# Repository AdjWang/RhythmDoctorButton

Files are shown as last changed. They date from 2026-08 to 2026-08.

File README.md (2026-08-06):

# Rhythm Doctor Button

<p align="center">
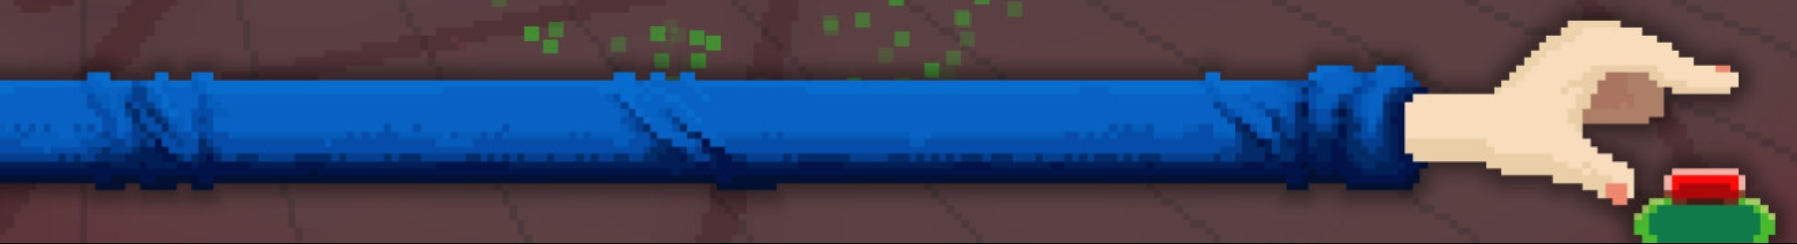
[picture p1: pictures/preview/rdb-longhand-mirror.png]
Mirrored ingame snapshot
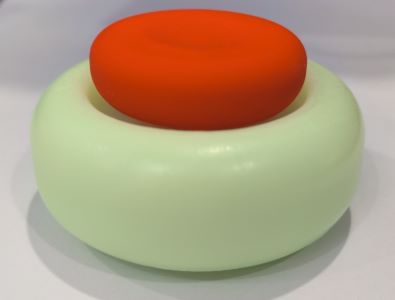
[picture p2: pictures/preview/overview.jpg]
Button overview
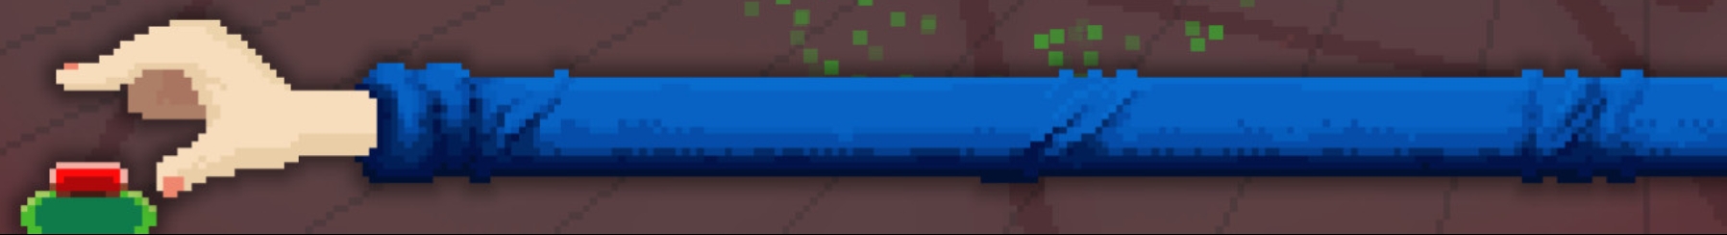
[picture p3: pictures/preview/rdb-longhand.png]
Ingame snapshot
  
</p>

一个用来玩[节奏医生](https://store.steampowered.com/app/774181/Rhythm_Doctor/)的按钮：

- Type-C 有线 + 蓝牙双模键盘，只有空格。
- 理论最长待机 34 天。
- 热插拔 5 脚机械轴。
- 模拟游戏按钮灯光。
- 串口可调灯光开关和亮度。

## 配置

- NRF52840 主控。
- 800 mAh 锂电池。
- 凯华 BOX 知秋轴。
- 1 颗轴体 LED，12 颗背光 LED。
- 磁吸底盖，带防滑脚垫。

## 工程文件

- firmware: 固件

- model: 外壳模型

- schematic: 电路 / PCB 图

制作流程参考 [make.md](make.md)

<h1 align="center">好了，废话不多说，Rhythm Doctor, 启动！</h1>

<p align="center">
  Rhythm Doctor button animation
</p>

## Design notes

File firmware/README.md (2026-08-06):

# Firmware

## Setup environment

Guide: https://docs.zephyrproject.org/4.4.0/develop/getting_started/index.html

```
uv init
uv add west
uv run west update
uv run west packages pip | xargs uv pip install
```

## Build

```
uv run west build -p always -b nrf52840dk/nrf52840 app -- -DAPP_BIN=main
```

Tests:

```
uv run west build -p always -b nrf52840dk/nrf52840 app -- -DAPP_BIN=uart
uv run west build -p always -b nrf52840dk/nrf52840 app -- -DAPP_BIN=cmd
uv run west build -p always -b nrf52840dk/nrf52840 app -- -DAPP_BIN=storage
uv run west build -p always -b nrf52840dk/nrf52840 app -- -DAPP_BIN=pwm_led
uv run west build -p always -b nrf52840dk/nrf52840 app -- -DAPP_BIN=key
uv run west build -p always -b nrf52840dk/nrf52840 app -- -DAPP_BIN=adc
uv run west build -p always -b nrf52840dk/nrf52840 app -- -DAPP_BIN=usb
uv run west build -p always -b nrf52840dk/nrf52840 app -- -DAPP_BIN=ble
```

## Flash program

```
cp build/zephyr/zephyr.uf2 /media/$USER/NICENANO/
```

## Flash bootloader

```
pyocd flash -t nrf52840 -f 1M -e chip --format hex scripts/nice_nano_bootloader-0.11.0_s140_6.1.1.hex
```

## Power consumption

- BLE connected, idle: 0.96 mA
- BLE connected, all leds on: 35.75 mA
- BLE advertising, without led: 1.27 mA

## Persisted settings

Uart on usb cdc is enabled to set arguments through console. Input `key = value` then enter to new line to accept.

Available settings:

- enable_led = true/false
- key_led_brightness = 0.0~1.0
- bkg_led_brightness = 0.0~1.0
- factory_reset = true

Default value:

- enable_led = true
- key_led_brightness = 0.2
- bkg_led_brightness = 0.08

> Adjust led brightness would change default power consumption.

Example outputs:

- Empty line:

    ```
    cmd parse error: code=cmd_empty_line message=empty command at position 0 in ''
    ```

- Set value:

    ```
    enable_led=false
    saved command: key=enable_led value=false
    ```

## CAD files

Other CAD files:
model/RhythmDoctorButton-v7.f3d

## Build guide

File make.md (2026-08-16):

# 制作流程

> 模型和电路在拍照留念后有小幅改动，最新版本细节可能与图片有所差异。

## 电路

使用[嘉立创 `EDA`](https://lceda.cn/)绘制，电路图 `DRC` 生成 `1` 个电源网络短接警告，`PCB` `DRC` 生成多个板载天线的连接和间距警告，均可忽略，希望软件后续版本可以妥善处理这些场景。

<p align="center">
  Schematic
</p>

<p align="center">
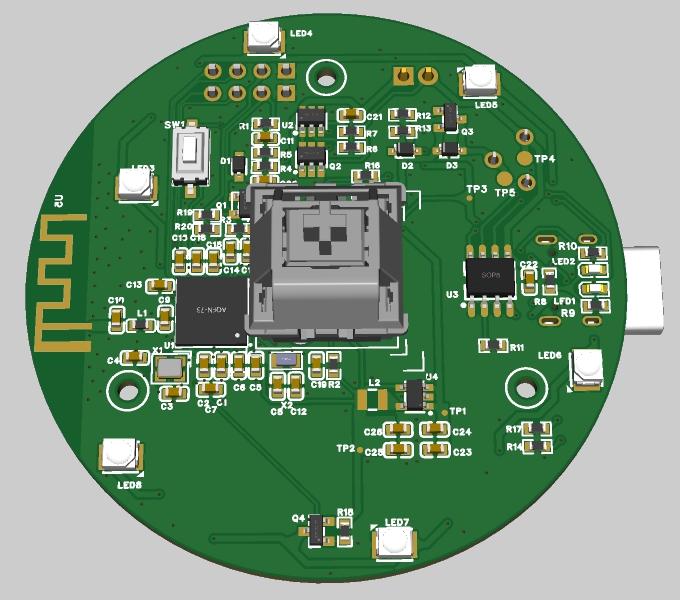
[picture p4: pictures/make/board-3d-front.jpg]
Board 3d front
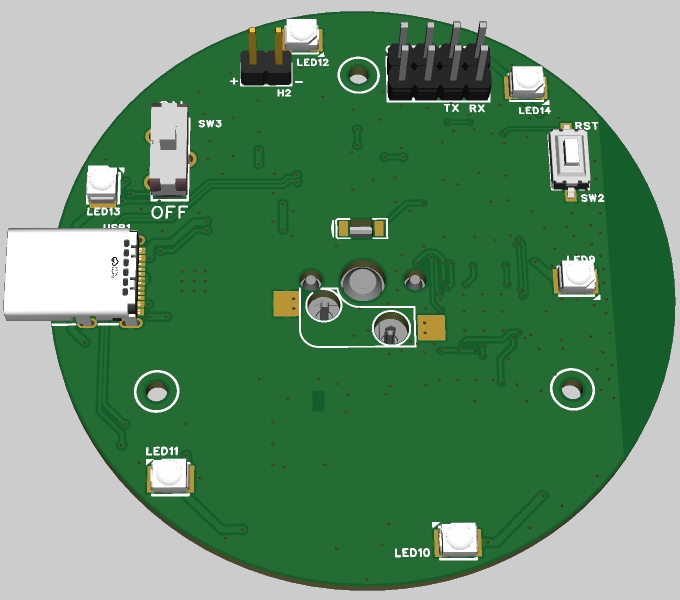
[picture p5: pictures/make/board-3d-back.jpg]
Board 3d back
  
</p>

焊接，安装电池。

<p align="center">
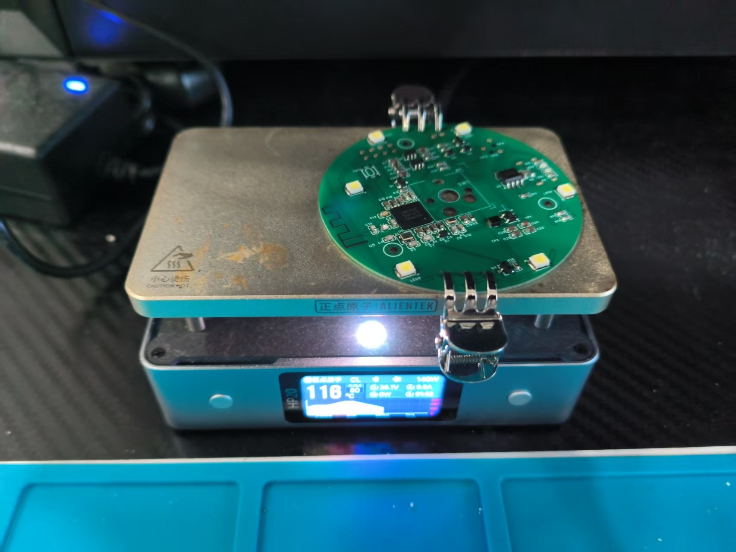
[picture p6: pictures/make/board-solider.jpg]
Board solider
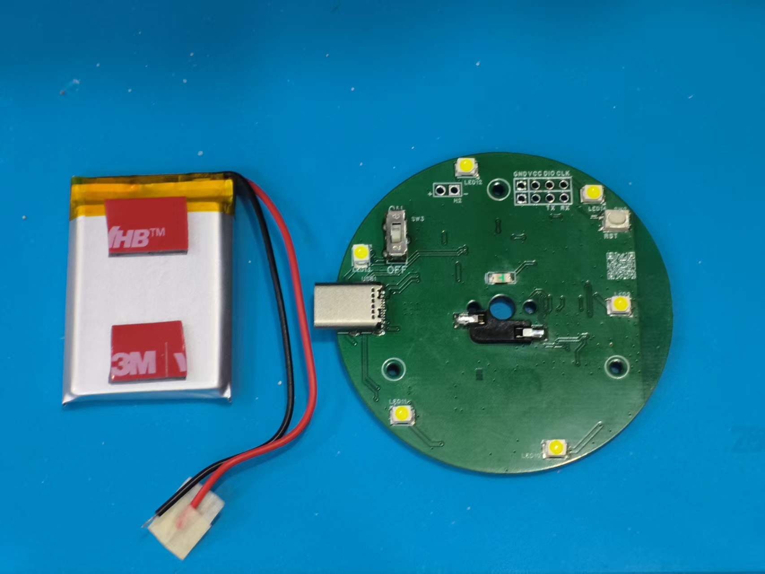
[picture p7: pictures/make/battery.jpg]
Add battery
  
</p>

成品电路板。

<p align="center">
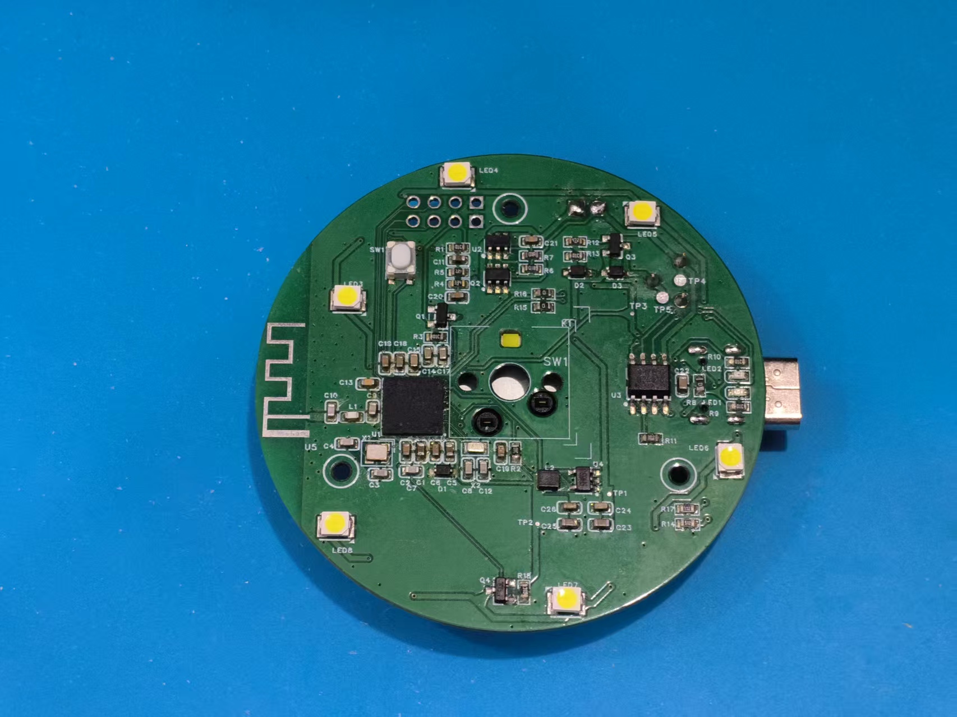
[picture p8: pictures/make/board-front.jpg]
Board front
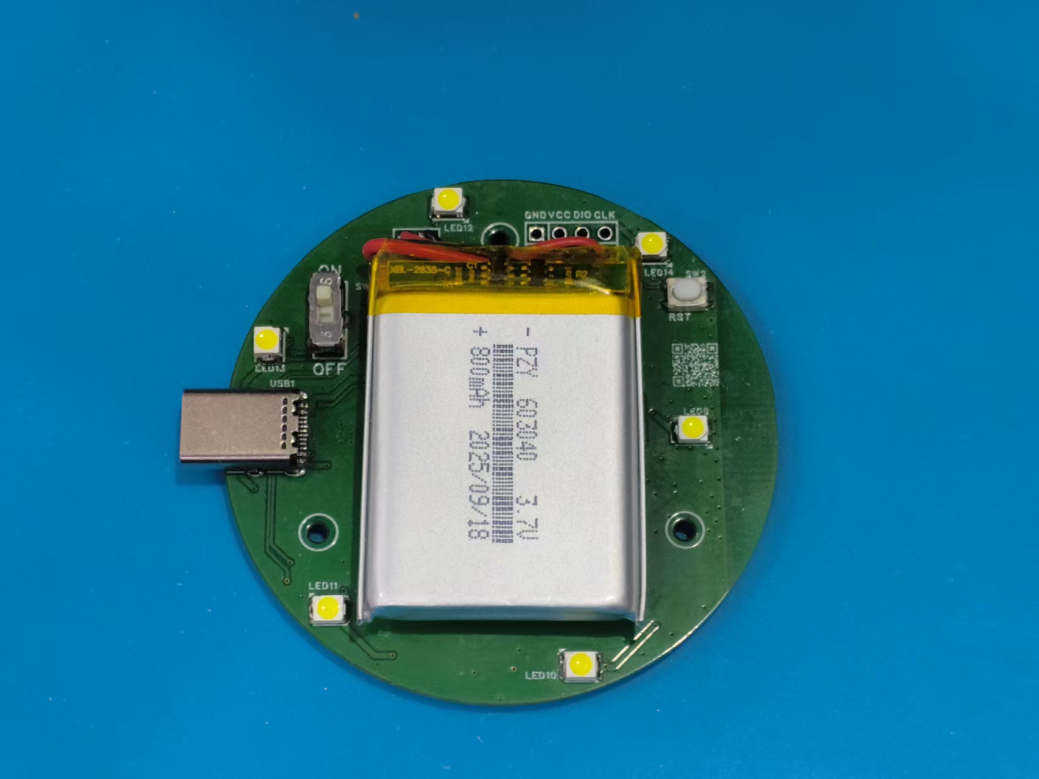
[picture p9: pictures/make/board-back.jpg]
Board back
  
</p>

### 注意事项：

- 材质使用 `FR-4` 即可。
- 板厚 `1mm`。
- `USB Type-C` 座子要选用加长款，当前用料 `MC-121-L124`。
- 用于 `ADC` 电池电压检测的分压电阻精度必须不低于 `1%`。
- 复位按钮在板子正反面都留了位置，功能相同，正面的只用于调试，成品只焊接背面的即可。
- 固定电池使用的 `2 mm` 厚双面胶建议使用 `3M VHB 4991` 无痕双面胶。常见的白色泡棉双面胶质量太差，一段时间后胶面会脱离泡棉导致电池脱落。

## 固件

电路板上预留了两排 `2.54mm` 的孔位，分别是 `SWD` 和串口。因为外壳空间有限，所以建议使用测试夹，不要焊接排针。

安装环境，编译，使用 `JLINK` 或者 `DAPLINK` 给芯片烧录 `bootloader` 然后下载 `uf2` 固件。

<p align="center">
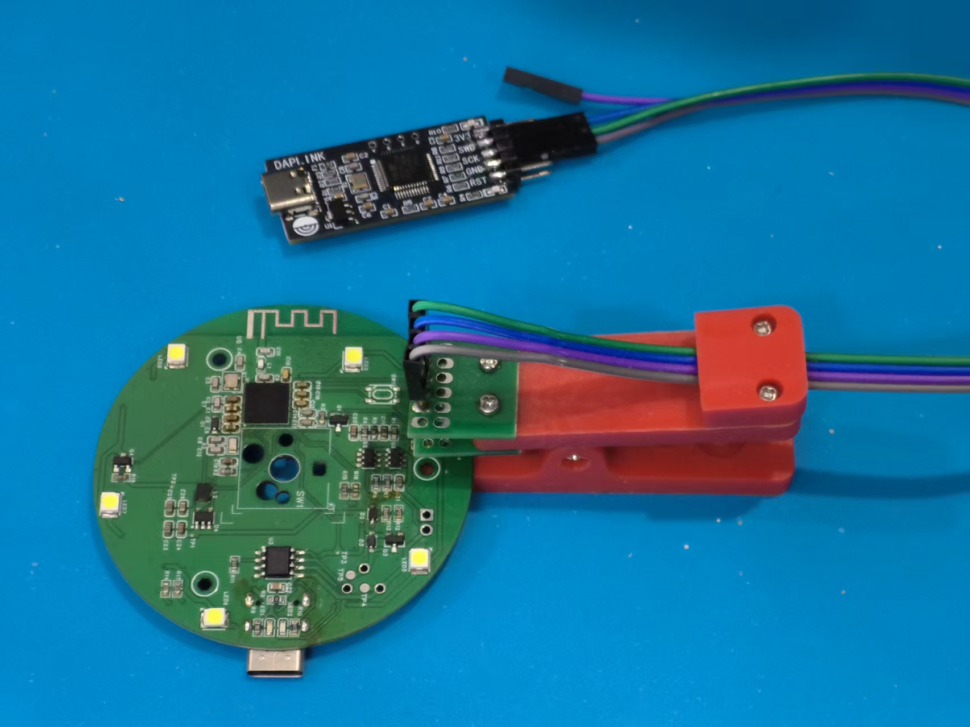
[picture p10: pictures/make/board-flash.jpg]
Debugging clip
  
</p>

## 外壳

外壳使用 `Fusion 360` 绘制，分为四部分：上盖，按钮盖，壳体和底盖。委托[嘉立创 3D 打印](https://www.jlc-3dp.cn/)代加工，使用光固化 3D 打印工艺，上盖选用 `8001` 透明树脂，喷油；按钮盖选用 `JLC` 全彩树脂，颜色 `RGB 245,14,22`；壳体和底盖选用 `8228` 浅绿色树脂，打磨。

除壳体外的材料：

- 碳钢 `M2*5` 螺栓 `3`个。
- 圆柱形磁铁，直径 `4 mm`，高度 `8 mm` `3` 个。
- 半球形硅胶防滑垫 `6*2mm` `3` 个。

<p align="center">
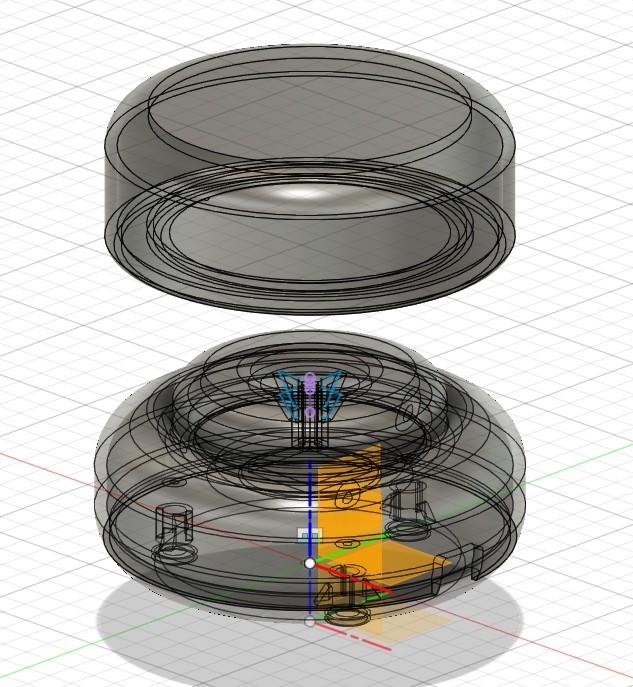
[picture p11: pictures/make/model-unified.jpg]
Model unified
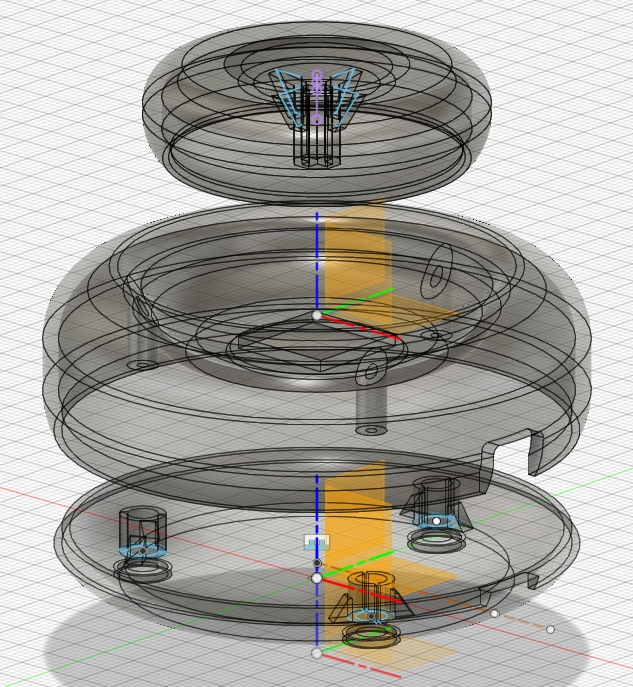
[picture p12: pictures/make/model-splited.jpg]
Model splited
  
</p>

壳体上有 `3` 个 `M2` 螺栓孔，需要手动攻丝。因为底座的磁铁需要吸附到螺栓，所以螺栓材质一定要使用强磁性的，比如碳钢，不能用弱磁性材料，比如不锈钢。

<p align="center">
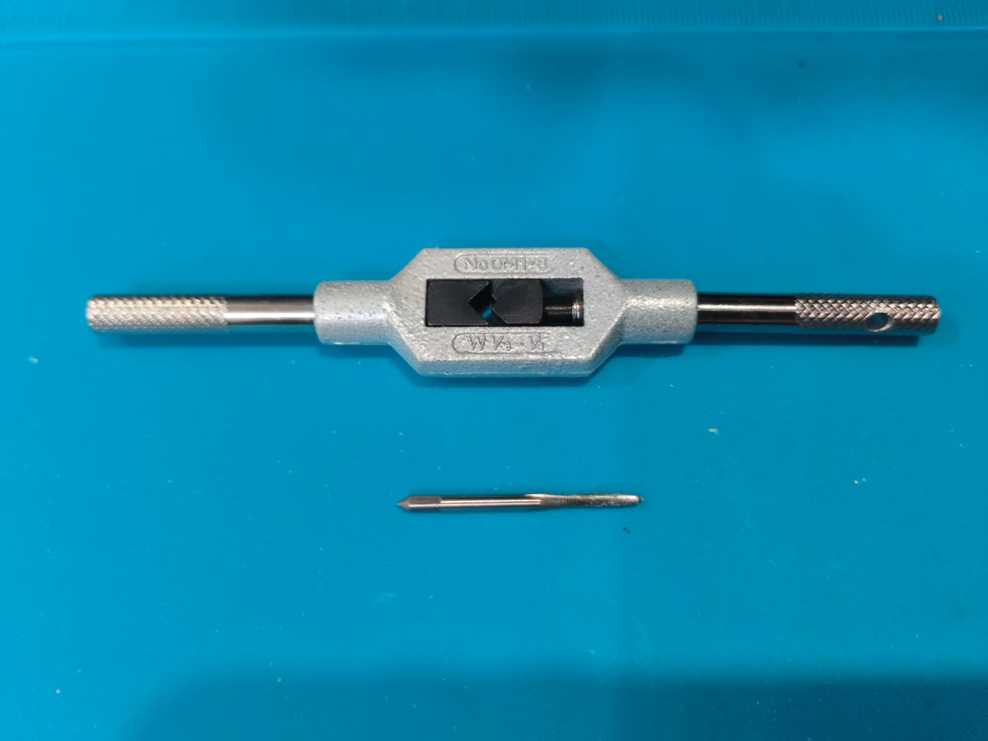
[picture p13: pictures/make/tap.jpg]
Tap
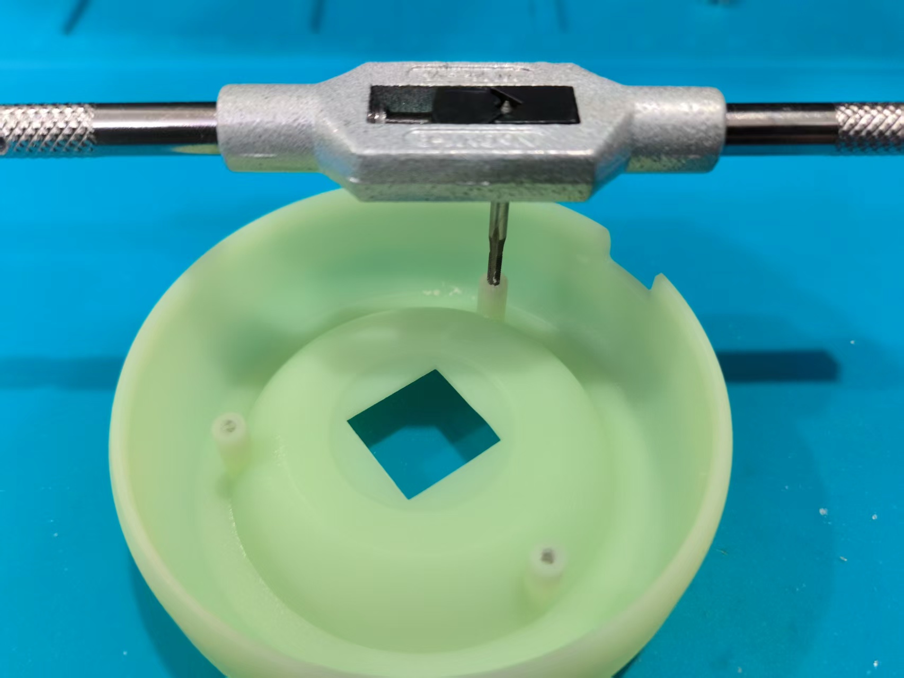
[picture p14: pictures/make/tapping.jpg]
Tapping
  
</p>

把圆柱磁铁安装到底盖的空位里。磁铁孔位做成通孔，方便拆卸磁铁。

<p align="center">
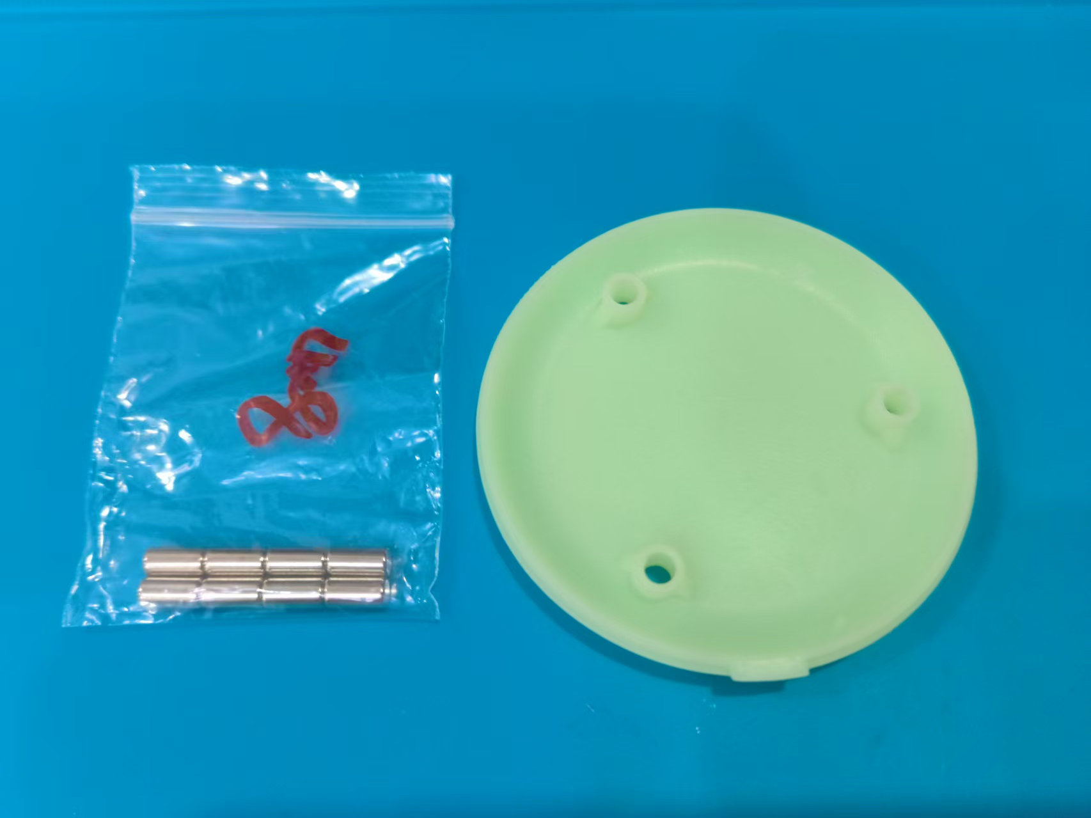
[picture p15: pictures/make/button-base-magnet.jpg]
Magnet
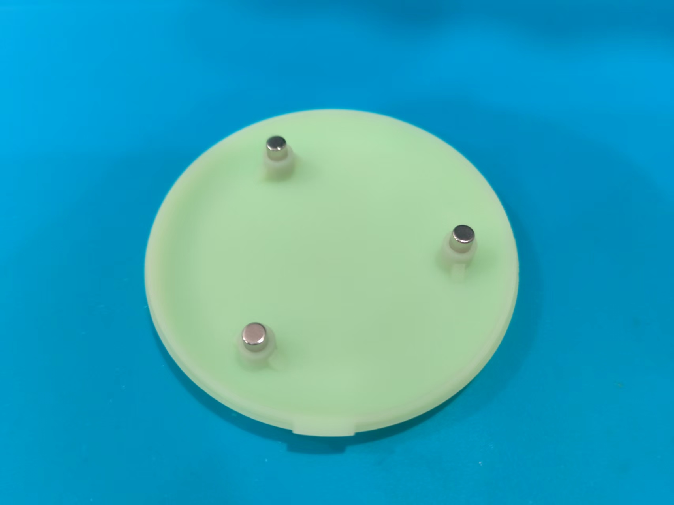
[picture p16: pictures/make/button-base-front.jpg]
Added view
  
</p>

给底盖贴装防滑硅胶垫。

<p align="center">
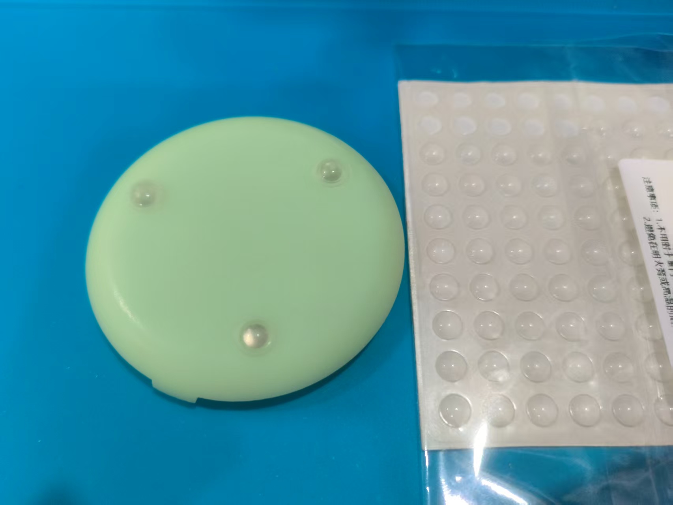
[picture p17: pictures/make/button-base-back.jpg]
Add anti-slip pad
  
</p>

### 注意事项：

- 丝锥太小，塑料材质也比较软，排屑困难，大约每进给 `3 mm` 左右需要退出来手动清理下丝锥排屑槽，不然容易滑牙。

## 总装

<p align="center">
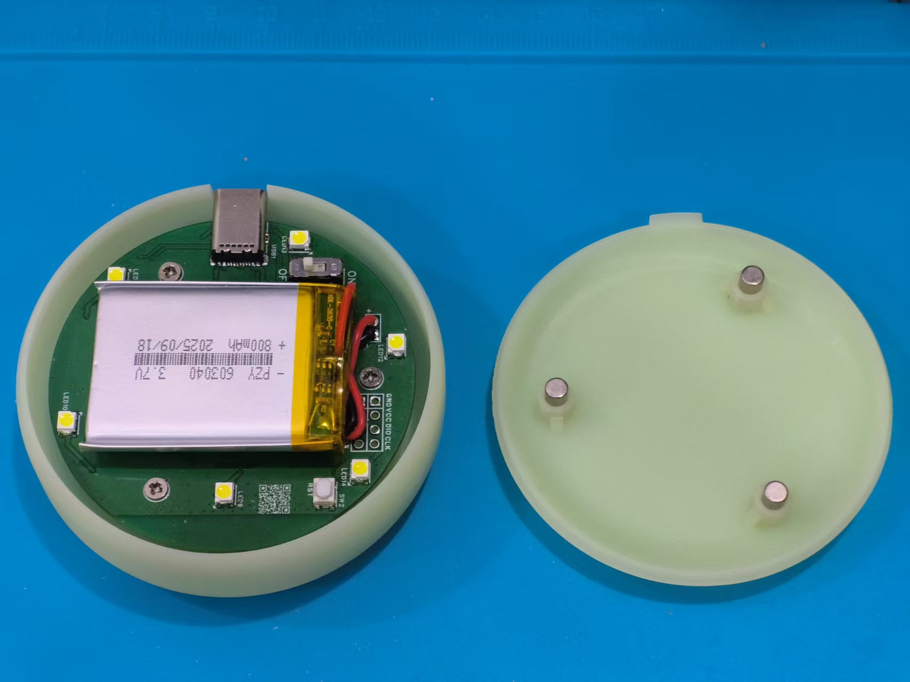
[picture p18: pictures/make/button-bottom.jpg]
Buttom view
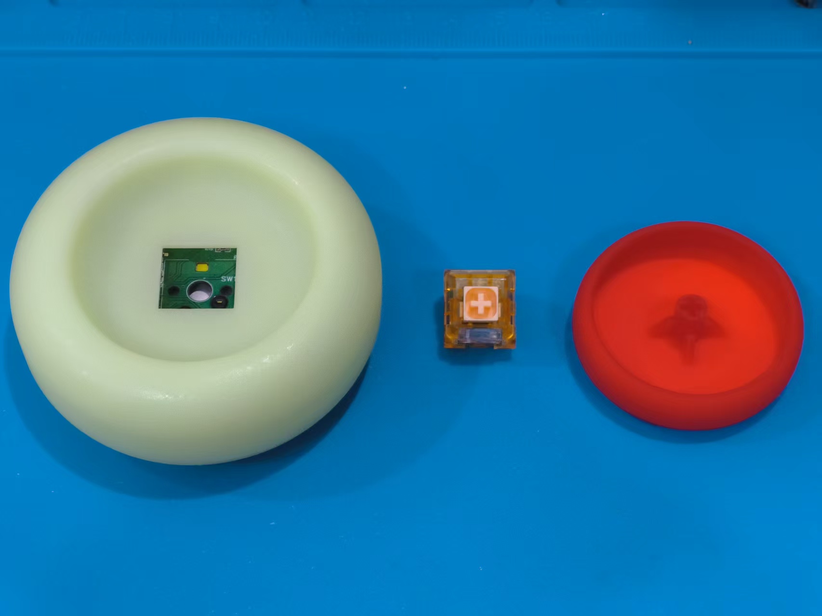
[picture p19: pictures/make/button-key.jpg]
Key view
  
</p>

<p align="center">
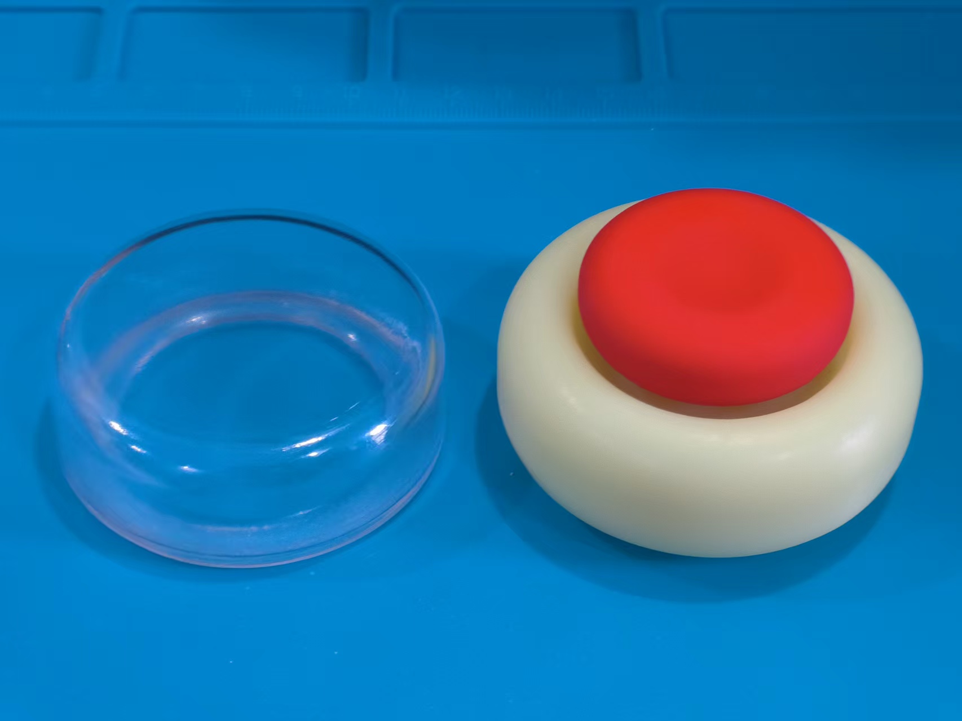
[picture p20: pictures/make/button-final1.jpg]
Buttom final view without lid
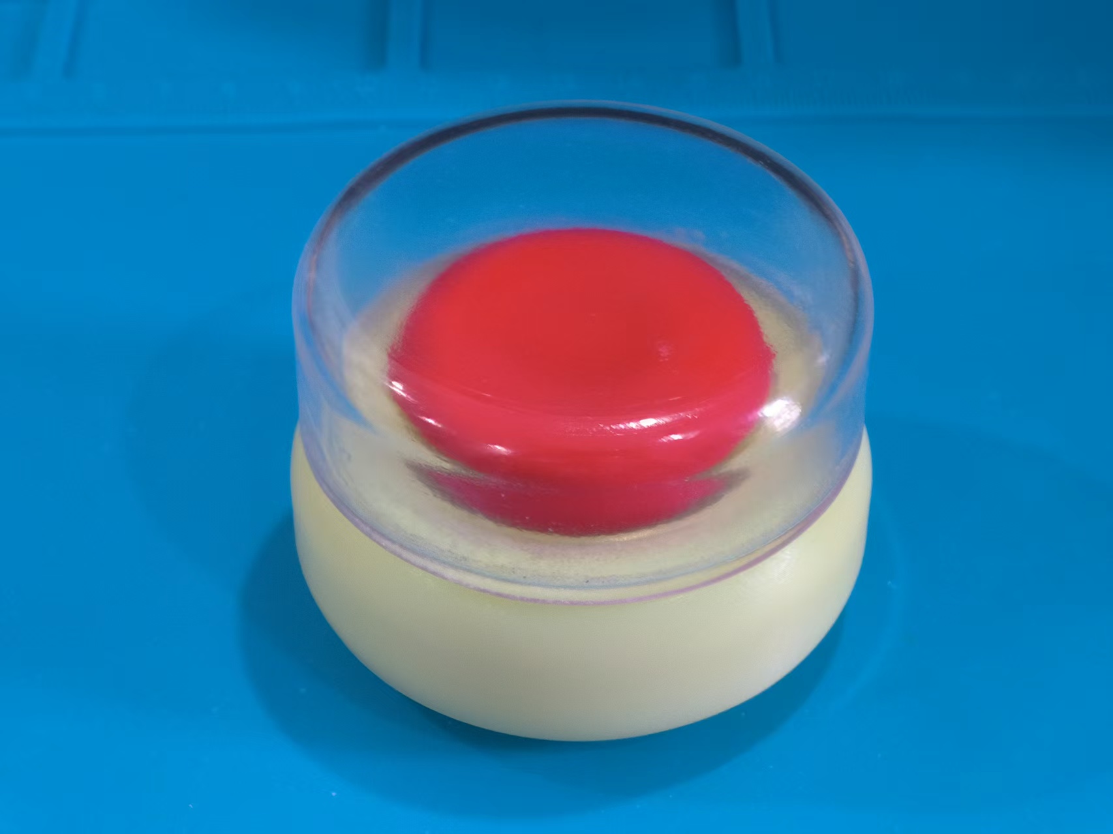
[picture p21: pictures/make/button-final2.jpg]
Button final view with lid
  
</p>

按钮整体高度略高，一直抬着手腕不是很舒服，所以上盖设计高度 `2.4cm`，玩的时候用来当托腕，平时当防尘盖。

扫描蓝牙设备，连接 `RhythmDoctorButton`，也可以不用蓝牙，直接用有线连接。如果同时连接，使用有线传输数据。

<p align="center">
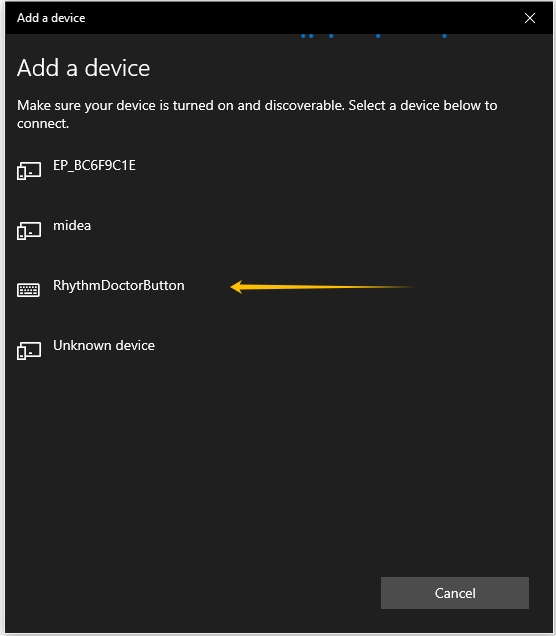
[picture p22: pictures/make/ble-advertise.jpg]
Ble advertise
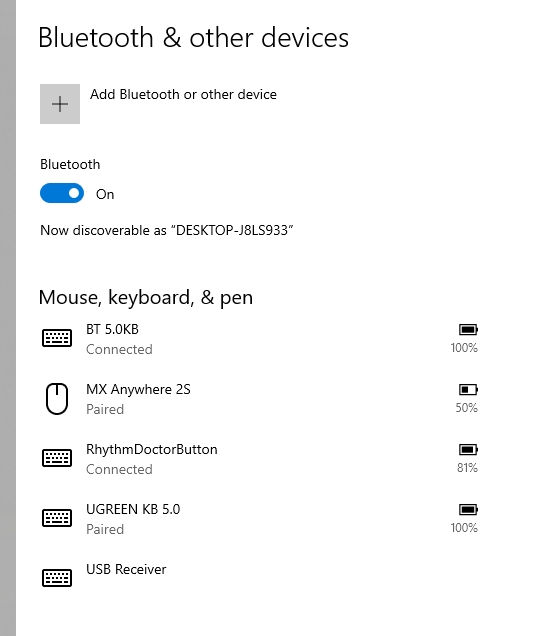
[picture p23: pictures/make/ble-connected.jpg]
Ble connected
  
</p>

Rhythm Doctor, 启动！

<p align="center">
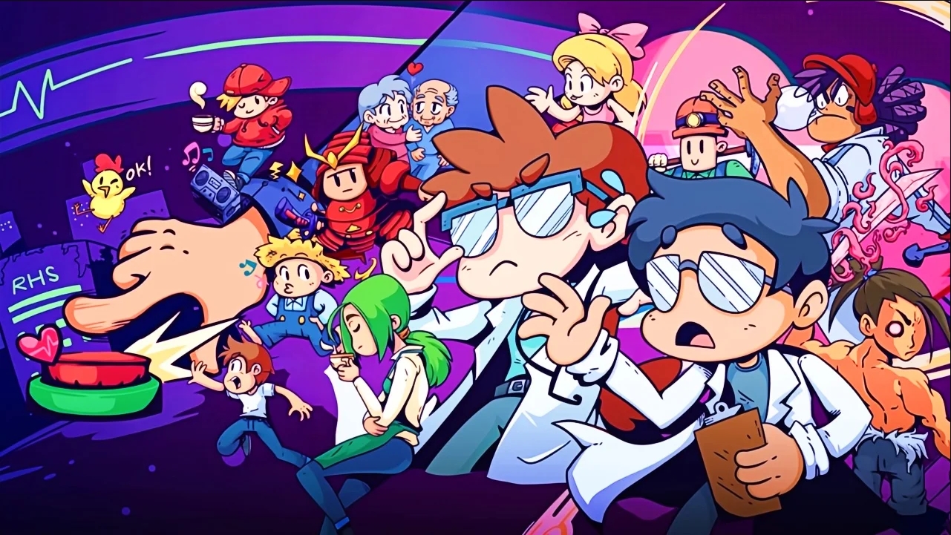
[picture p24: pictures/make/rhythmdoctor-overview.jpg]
Rhythm Doctor overview
  
</p>

<p align="center">
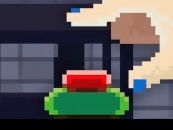
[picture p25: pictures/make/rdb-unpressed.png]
Ingame unpressed snapshot
  Ingame pressed snapshot
</p>

<p align="center">
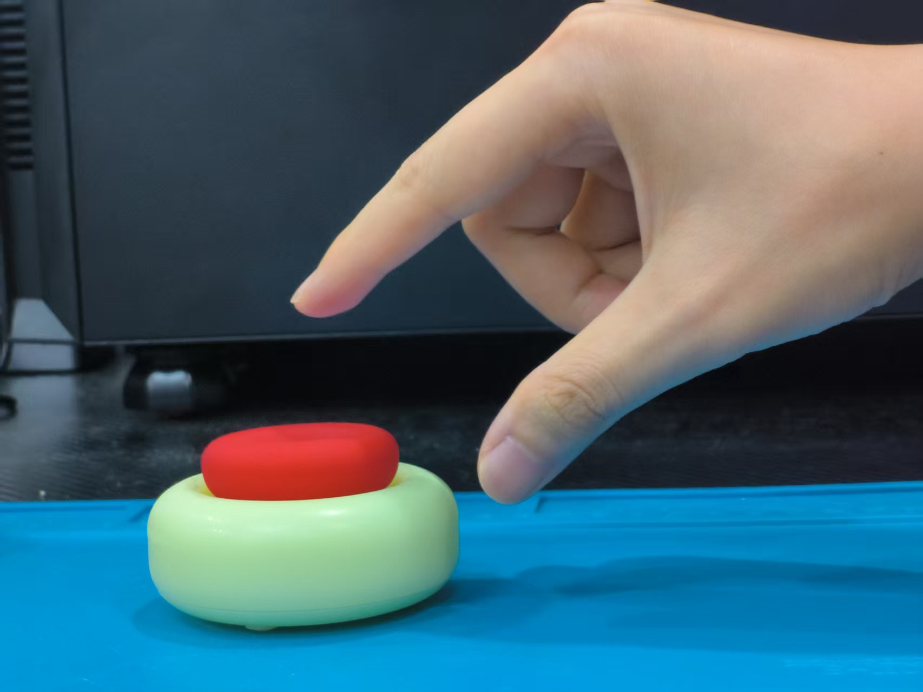
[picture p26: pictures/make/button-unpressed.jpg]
Test unpressed
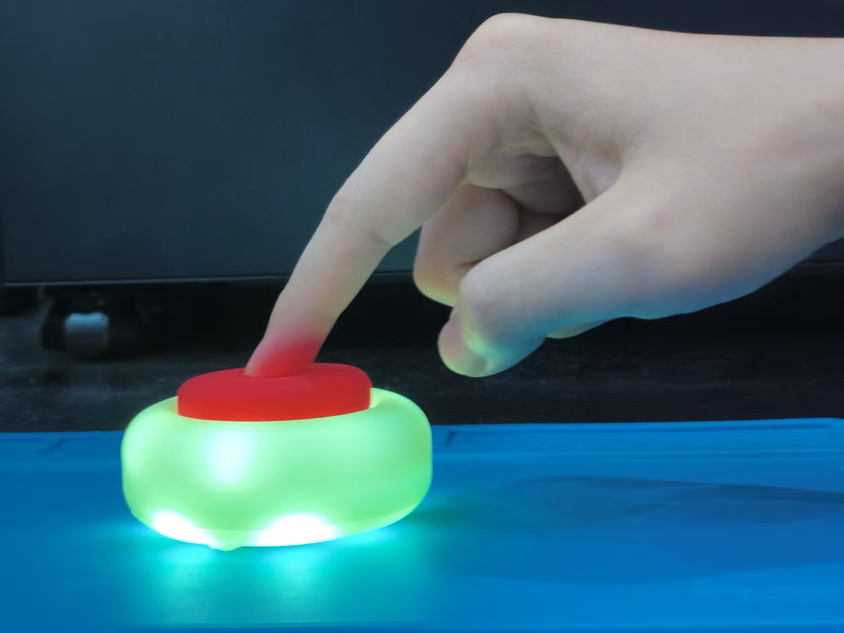
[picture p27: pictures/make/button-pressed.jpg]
Test pressed
  
</p>

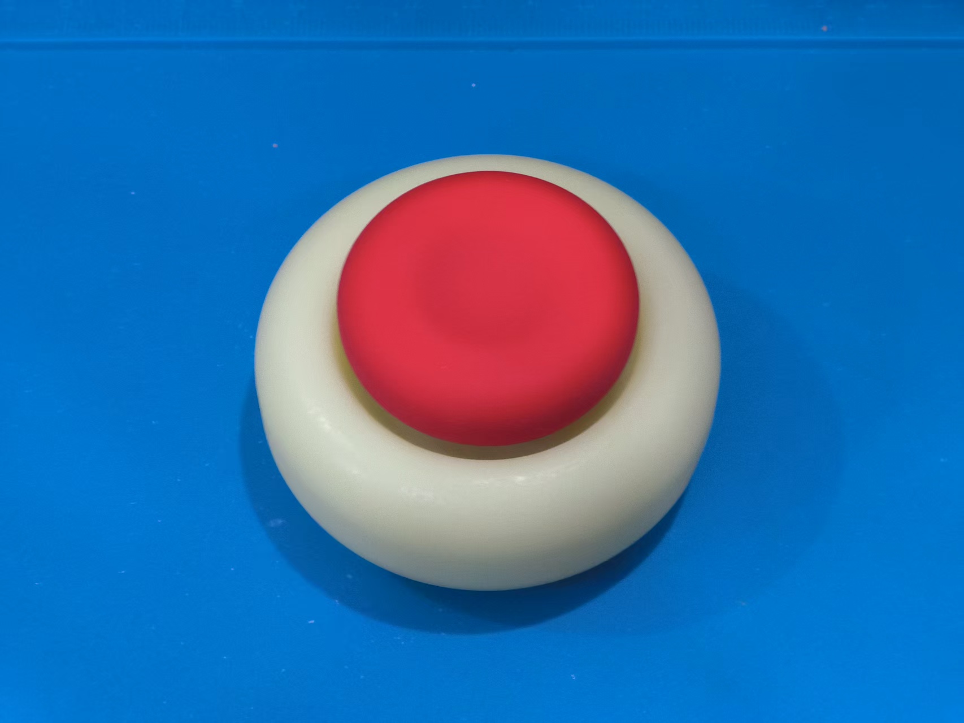
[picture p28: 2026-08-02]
pictures/make/button.jpg

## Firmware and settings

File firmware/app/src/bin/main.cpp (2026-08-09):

#include <memory>
#include <optional>
#include <string_view>

#include <zephyr/devicetree.h>
#include <zephyr/drivers/adc.h>
#include <zephyr/drivers/gpio.h>
#include <zephyr/drivers/pwm.h>
#include <zephyr/drivers/uart.h>
#include <zephyr/kernel.h>
#include <zephyr/sys/printk.h>

#include "battery_adc.h"
#include "button.h"
#include "cmd.h"
#include "keyboard/keyboard.h"
#include "keyboard/usb_device.h"
#include "light.h"
#include "setting.h"

BUILD_ASSERT(DT_NODE_HAS_COMPAT(DT_CHOSEN(zephyr_console),
                                zephyr_cdc_acm_uart),
             "Console device must be a USB CDC ACM UART");

namespace {
static constexpr uint32_t kMainLoopDelayMs = 10;
static constexpr uint32_t kBatLevelReportDurationMs = 1000;
// Force advertising flash even when led is configured off.
static constexpr float kAdvertisingFlashBrightness = 0.5f;

constexpr gpio_dt_spec kMainButton =
    GPIO_DT_SPEC_GET(DT_ALIAS(main_btn), gpios);
constexpr pwm_dt_spec kBkgLed = PWM_DT_SPEC_GET(DT_ALIAS(bkg_led));
constexpr pwm_dt_spec kKeyLed = PWM_DT_SPEC_GET(DT_ALIAS(key_led));
constexpr adc_dt_spec kBatteryAdc =
    ADC_DT_SPEC_GET(DT_PATH(zephyr_user));

std::unique_ptr<rdb::IKeyboard> ble_keyboard;
std::unique_ptr<rdb::IKeyboard> usb_keyboard;
rdb::IKeyboard* keyboard = nullptr;

rdb::Button main_btn(kMainButton);
rdb::BatteryAdc bat_adc(kBatteryAdc);
rdb::Light bkg_led(kBkgLed);
rdb::Light key_led(kKeyLed);
rdb::LightFlasher advertising_flash;
rdb::LightFlasher bkg_flash;
rdb::AppSettings& app_settings = rdb::AppSettings::Instance();
rdb::CmdParser cmd_parser;
const device* console = DEVICE_DT_GET(DT_CHOSEN(zephyr_console));

uint32_t last_report_time_ms = 0;
bool cmd_console_connected = false;

void InspectKeyboardMode() {
  if (usb_keyboard != nullptr && keyboard == usb_keyboard.get()) {
    printk("Using USB HID keyboard\n");
  } else if (ble_keyboard != nullptr && keyboard == ble_keyboard.get()) {
    printk("Using Bluetooth keyboard\n");
  } else if (keyboard == nullptr) {
    printk("Keyboard unplugged\n");
  } else {
    printk("Invalid keyboard mode\n");
  }
}

void PrintView(const std::string_view text) {
  printk("%.*s", static_cast<int>(text.size()), text.data());
}

void PrintCmdError(const rdb::Error& error) {
  printk("cmd parse error: code=");
  PrintView(rdb::ToString(error.code));
  printk(" message=");
  PrintView(error.message);
  printk("\n");
}

void PrintSettingsError(const rdb::AppSettings::Error& error) {
  printk("settings error: operation=%s code=%d\n", error.operation,
         error.code);
}

void HandleCommandResult(const rdb::CmdParser::Result& result) {
  if (!result.has_value()) {
    PrintCmdError(result.error());
    return;
  }
  const auto save_result = app_settings.SaveCommand(*result);
  if (!save_result.has_value()) {
    PrintSettingsError(save_result.error());
    return;
  }
  printk("saved command: key=");
  PrintView(result->key);
  printk(" value=");
  PrintView(result->value_text);
  printk("\n");
}

void UpdateCommands() {
  if (!device_is_ready(console)) {
    return;
  }
  uint32_t dtr = 0;
  // The full app prints boot logs through the same CDC UART used for commands.
  // Wait for a real terminal session and drain stale bytes so those logs are not
  // parsed as the first command.
  if (uart_line_ctrl_get(console, UART_LINE_CTRL_DTR, &dtr) != 0 || dtr == 0) {
    if (cmd_console_connected) {
      cmd_parser.Reset();
      cmd_console_connected = false;
    }
    return;
  }
  uint8_t byte = 0;
  if (!cmd_console_connected) {
    cmd_parser.Reset();
    cmd_console_connected = true;
    (void)uart_line_ctrl_set(console, UART_LINE_CTRL_DCD, 1);
    (void)uart_line_ctrl_set(console, UART_LINE_CTRL_DSR, 1);
    while (uart_poll_in(console, &byte) == 0) {
    }
    printk("cmd console ready\n");
    return;
  }
  while (uart_poll_in(console, &byte) == 0) {
    if (byte == '\r' || byte == '\n') {
      printk("\n");
    } else if (byte == '\b' || byte == 0x7f) {
      printk("\b \b");
    } else if (byte >= ' ' && byte <= '~') {
      (void)uart_poll_out(console, byte);
    }
    if (const std::optional<rdb::CmdParser::Result> result =
            cmd_parser.Feed(static_cast<char>(byte))) {
      HandleCommandResult(*result);
    }
  }
}

void OnMainButtonPress() {
  printk("Press button\n");
  if (app_settings.values().enable_led) {
    key_led.SetBrightness(app_settings.values().key_led_brightness);
    bkg_flash.Reset();
  }
  if (keyboard != nullptr && keyboard->is_connected()) {
    keyboard->Press(' ');
  }
}

void OnMainButtonRelease() {
  printk("Release button\n");
  key_led.SetBrightness(0.0f);
  if (keyboard != nullptr && keyboard->is_connected()) {
    keyboard->Release(' ');
  }
}

void EnableAdvertisingFlash() {
  advertising_flash.Reset();
}

void DisableAdvertisingFlash() {
  advertising_flash.Reset();
  key_led.SetBrightness(0.0f);
}

void Setup() {
  main_btn.Begin();
  main_btn.set_on_press(OnMainButtonPress);
  main_btn.set_on_release(OnMainButtonRelease);
  if (const auto result = app_settings.LoadOrWriteDefaults();
      !result.has_value()) {
    PrintSettingsError(result.error());
  }
  app_settings.RegisterCommands(cmd_parser);
  bat_adc.Begin();
  bkg_led.Begin();
  key_led.Begin();
  advertising_flash.SetPattern({
      {1.0f, 100},    // fully on for 100ms
      {0.0f, 1400},   // fully off for 1400ms
  }, /*loop*/ true);
  bkg_flash.SetPattern({
      {1.0f, 40},
      {0.7f, 20},
      {0.3f, 20},
      {0.0f, 10},
  }, /*loop*/ false);
  // Initialize as closed.
  bkg_flash.Reset(-1);
  usb_keyboard = std::make_unique<rdb::UsbKeyboard>(rdb::GetUsbHidDevice());
  usb_keyboard->Begin();
  ble_keyboard = std::make_unique<rdb::BleKeyboard>(
      CONFIG_BT_DEVICE_NAME, CONFIG_BT_DIS_MANUF_NAME_STR);
  ble_keyboard->Begin();
}

void Loop() {
  const uint32_t now_ms = static_cast<uint32_t>(k_uptime_get());
  // Receive setting commands.
  UpdateCommands();
  // Update button state.
  main_btn.Update();
  // Send battery level.
  bat_adc.Update();
  if (now_ms - last_report_time_ms > kBatLevelReportDurationMs) {
    last_report_time_ms = now_ms;
    const uint8_t level = bat_adc.battery_level();
    if (ble_keyboard != nullptr) {
      ble_keyboard->SetBatteryLevel(level);
    }
  }
  // Select keyboard.
  if (usb_keyboard != nullptr && usb_keyboard->is_connected()) {
    if (keyboard != usb_keyboard.get()) {
      keyboard = usb_keyboard.get();
      InspectKeyboardMode();
      DisableAdvertisingFlash();
    }
  } else if (ble_keyboard != nullptr && ble_keyboard->is_connected()) {
    if (keyboard != ble_keyboard.get()) {
      keyboard = ble_keyboard.get();
      keyboard->ReleaseAll();
      InspectKeyboardMode();
      DisableAdvertisingFlash();
    }
  } else {
    if (keyboard != nullptr) {
      keyboard = nullptr;
      InspectKeyboardMode();
      EnableAdvertisingFlash();
    }
    // Flash key led to show advertising state.
    advertising_flash.Update(now_ms);
    key_led.SetBrightness(kAdvertisingFlashBrightness *
                          advertising_flash.get_brightness_ratio());
  }
  // Flash background led.
  bkg_flash.Update(now_ms);
  bkg_led.SetBrightness(app_settings.values().bkg_led_brightness *
                        bkg_flash.get_brightness_ratio());
}

}  // namespace

int main() {
  printk("RhythmDoctorButton nRF52840 starting\n");
  Setup();
  while (true) {
    Loop();
    k_msleep(kMainLoopDelayMs);
  }
}

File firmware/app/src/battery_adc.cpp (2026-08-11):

#include "battery_adc.h"

#include <algorithm>

#include <zephyr/kernel.h>
#include <zephyr/sys/printk.h>

namespace rdb {

BatteryAdc::BatteryAdc(const adc_dt_spec& adc) : adc_(adc) {}

uint8_t BatteryAdc::battery_level() const {
  uint32_t sum = 0;
  for (const uint8_t level : battery_level_samples_) {
    sum += level;
  }
  return static_cast<uint8_t>(sum / battery_level_samples_.size());
}

void BatteryAdc::Begin() {
  if (!adc_is_ready_dt(&adc_)) {
    printk("Battery ADC is not ready\n");
    return;
  }

  int ret = adc_channel_setup_dt(&adc_);
  if (ret != 0) {
    printk("Failed to configure battery ADC channel (%d)\n", ret);
    return;
  }

  initialized_ = true;
  for (uint8_t& sample : battery_level_samples_) {
    sample = ReadBatteryLevel();
  }
}

void BatteryAdc::Update() {
  if (!initialized_) {
    return;
  }

  const uint32_t now_ms = static_cast<uint32_t>(k_uptime_get());
  constexpr uint32_t kSamplePeriodMs = 1000 / kBatterySampleFreqHz;
  if (now_ms - last_sample_time_ms_ <= kSamplePeriodMs) {
    return;
  }

  last_sample_time_ms_ = now_ms;
  battery_level_samples_[sample_index_] = ReadBatteryLevel();
  sample_index_ = (sample_index_ + 1) % battery_level_samples_.size();
}

uint8_t BatteryAdc::ReadBatteryLevel() {
  int16_t raw_value = 0;
  adc_sequence sequence = {
      .buffer = &raw_value,
      .buffer_size = sizeof(raw_value),
  };
  int ret = adc_sequence_init_dt(&adc_, &sequence);
  if (ret != 0) {
    printk("Failed to initialize battery ADC sequence (%d)\n", ret);
    return 0;
  }
  ret = adc_read_dt(&adc_, &sequence);
  if (ret != 0) {
    printk("Battery ADC read failed (%d)\n", ret);
    return 0;
  }
  int32_t adc_mv = raw_value;
  ret = adc_raw_to_millivolts_dt(&adc_, &adc_mv);
  if (ret != 0) {
    printk("Battery ADC conversion failed (%d)\n", ret);
    return 0;
  }
  const auto battery_mv =
      static_cast<uint32_t>(static_cast<float>(adc_mv) / kSampleRatio);
  if (battery_mv < kBatteryMinVoltageMv) {
    return 0;
  }
  float ratio =
      static_cast<float>(battery_mv - kBatteryMinVoltageMv) /
      static_cast<float>(kBatteryMaxVoltageMv - kBatteryMinVoltageMv);
  ratio = std::clamp(ratio, 0.0f, 1.0f);
  return static_cast<uint8_t>(ratio * 100.0f);
}

}  // namespace rdb

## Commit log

2026-06-20 Fix test uart.
2026-07-13 Fix test uart without external 32.768khz crystal.
    [test_uart.cpp]
2026-07-26 Fix test pwm led.
2026-07-26 Fix cold start crash.
    [main.cpp]
2026-07-26 Setup pwm output initial value.
2026-07-26 Fix usb hid device context.
    [main.cpp]
2026-07-30 Fix usb setup && Adjust led brightness.
    [main.cpp]
2026-08-01 Disable usb to reduce current when usb not plugged in.
2026-08-01 Update readme power consumption.
2026-08-02 Add model and schematic files.
    [RhythmDoctorButton-v6.f3d]
2026-08-04 Add bkg led flash pattern.
2026-08-04 Update reset switch and esd diode.
2026-08-08 Update 3d print manufacturing process.
2026-08-11 Fix adc sample range.
    [battery_adc.cpp, battery_adc.h]
2026-08-16 Add lid.
    [RhythmDoctorButton-v6.f3d, RhythmDoctorButton-v7.f3d]
